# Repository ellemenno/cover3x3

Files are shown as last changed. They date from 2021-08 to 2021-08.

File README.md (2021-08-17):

# cover3x3
openscad program for a cover-up tic-tac-toe game

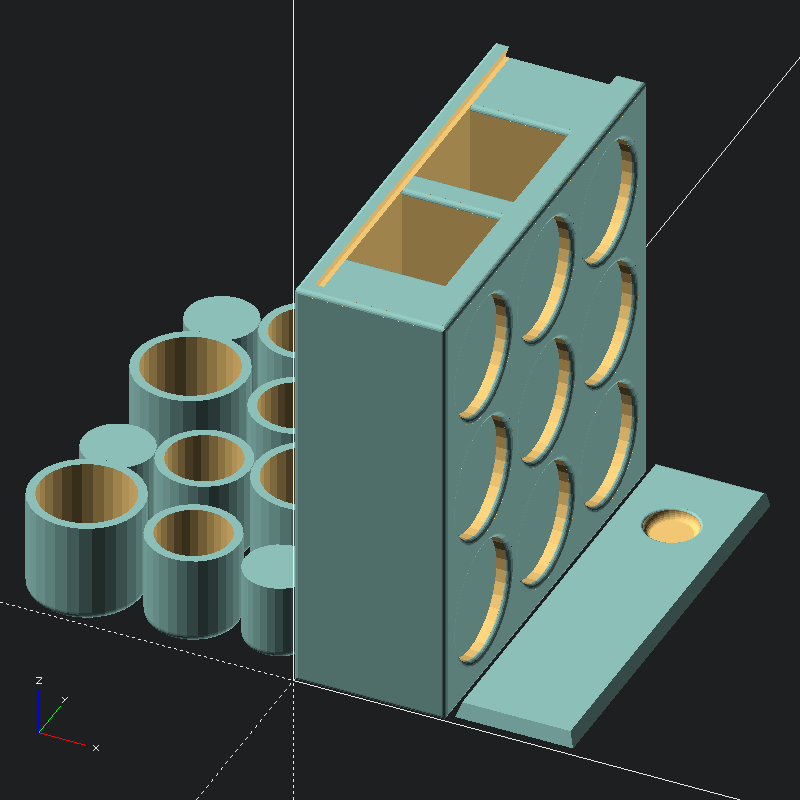
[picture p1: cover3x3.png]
cover3x3 board, box, and pieces


# pieces

* _board_ - 3x3 grid of squares, same as tic-tac-toe
* _cups_ - nesting pieces in 2 colors, each color having 2 each of 3 sizes. cups are played open side down, to cover smaller cups.
* _stack_ - a set of one or more nested cups

# rules

a game for 2 players

## start

the game starts with an empty board.

each player starts with 2 full stacks of the same color.

## play

players take turns placing cups of their color, either from one of their stacks onto the board, or from one location on the board to another.

moving from one board location to another may uncover a cup, which is then in play.

cups can be placed on empty squares, or to cover a cup of a smaller size of either color.

## finish

a player wins when there is a full row of their color, either horizontally, vertically, or diagonally.

winning may happen either as a result of a player's own move, or their opponent's.

if a position is repeted 3 times, the game ends in a draw.

# notes

* this openscad program depends on the [`slide_top_box` module][slide_top_box]
* Gobblet (4x4) and Gobblet Gobblers (3x3) are board games designed by Thierry Denoual and published by Blue Orange Games that introduced the cover mechanic.

[slide_top_box]: https://github.com/ellemenno/slide_top_box "openscad module for a sliding dovetail lidded box"
[thumbnail]: ./cover3x3.png "rendering of the game board and pieces"

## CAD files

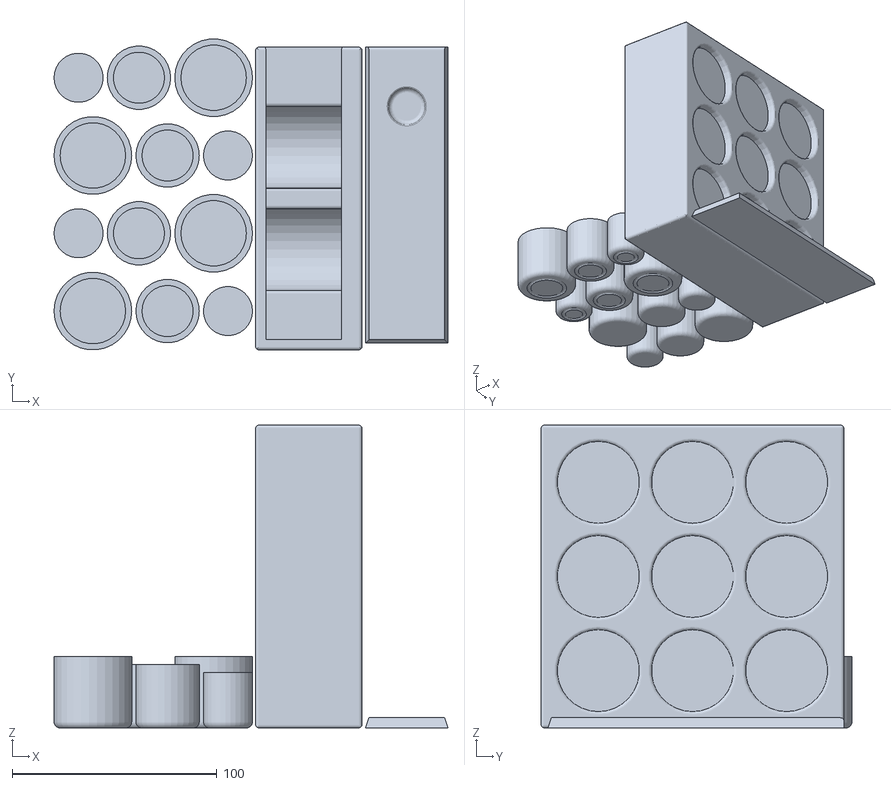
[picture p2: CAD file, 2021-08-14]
cover3x3.stl
192.5 x 151.9 x 148.0

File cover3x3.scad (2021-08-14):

//----------------------------
// cover3x3 game
// pieces fit inside gameboard
// v0.0.6


use <slide_top_box.scad>

//--- parameters

wall_thickness = 5;
piece_thickness = 3;
piece_spacing = 3;
sm_piece_diameter = 24;
air_gap = 1; // stacking clearance

// computed variables
sm = sm_piece_diameter;
md = sm+piece_thickness*2+air_gap; // medium
lg = md+piece_thickness*2+air_gap; // large
piece_height = sm_piece_diameter + piece_thickness;

board_dim = 3 * (lg+air_gap*2 + (piece_spacing*2));
box_size = slide_top_box_size(
  size=[lg_h(piece_height, piece_thickness, air_gap)+2*air_gap, board_dim, board_dim],
  thickness=wall_thickness,
  is_interior_size=true
);

//--- assembly

echo("- - - - - - - -");
echo("cover3x3");
ind = "    ";
echo(str(ind, "v0.0.6"));
echo(str(ind, "board size of ", box_size+[2*wall_thickness, 0, 0]));
echo(str(ind, [sm_piece_diameter, piece_height], "mm small piece"));
echo(str(ind, wall_thickness, "mm wall thickness"));
echo(str(ind, piece_thickness, "mm piece thickness"));
echo("- - - - - - - -");

// gameboard
color("white") box_and_gameboard(box_size, wall_thickness, [sm, md, lg], piece_spacing, air_gap);

// pieces, behind box
translate([-lg/2-piece_thickness/2, lg/2, 0]) {
  color("red")       translate([0,    0, 0]) piece_set(sm, md, lg, piece_height, piece_thickness, marked=true);
  color("royalblue") translate([0, lg*2, 0]) piece_set(sm, md, lg, piece_height, piece_thickness, marked=false);
}

//--- functions
function sm_h(h, t, a=1) = h;
function md_h(h, t, a=1) = h+t+a;
function lg_h(h, t, a=1) = h+t+a+t+a;

//--- modules

module torus(big_r=5, little_r=1.5, fs=0.5) {
  rotate_extrude($fs=fs)
  translate([big_r-little_r, 0, 0])
  circle(r=little_r, $fs=fs);
}

module round_inner(big_r=5, little_r=1.5, fs=0.5) {
  translate([0, 0, -little_r])
  difference() {
    cylinder(h=big_r, r=big_r, $fs=fs);
    torus(big_r+little_r, little_r, fs);
  }
}

module round_linear(len, f, fs=0.5) {
  translate([0, -f, -f])
  difference() {
    cube([len,f*2, f*2], center=false);
    rotate([0, 90, 0]) translate([0, 0, -len*0.05]) cylinder(h=len*1.1, r=f, $fs=fs);
  }
}

module piece(w, h, thickness, marked=true, solid=false, fs=0.5) {
  r = w/2;
  h1 = h-thickness;
  r1 = r-thickness;
  t = thickness;

  difference() {
    hull() {
      translate([0,0,t]) torus(big_r=r, little_r=t);
      translate([0, 0, h/2+t/2]) cylinder($fs=fs, h=h-t, r=r, center=true);
    }
    if (marked) {
      translate([0,0,-t/4]) torus(r*.7, t/2);
    }
    if (!solid) {
      translate([0, 0, h1/2+thickness+t]) cylinder($fs=fs, h=h, r=r1, center=true);
    }
  }
}

module piece_set(sm, md, lg, height, thickness, marked=true, air_gap=1) {
  a = air_gap;
  t = thickness;
  tt = thickness/2;
  h = height;
  gap = (lg-sm)/2;
  translate([              gap,  0, 0]) piece(sm, sm_h(h, t, a), t, marked, solid=true);
  translate([        gap-md+tt,  0, 0]) piece(md, md_h(h, t, a), t, marked);
  translate([gap-(md+lg)+tt+tt,  0, 0]) piece(lg, lg_h(h, t, a), t, marked);
  translate([                0, lg, 0]) piece(lg, lg_h(h, t, a), t, marked);
  translate([           -lg+tt, lg, 0]) piece(md, md_h(h, t, a), t, marked);
  translate([   -(lg+md)+tt+tt, lg, 0]) piece(sm, sm_h(h, t, a), t, marked, solid=true);
}

module hole_grid(diameter, spacing=2, air_gap=1, fs=0.5) {
  module hole_row(w, h, s) {
    translate([w*0+s*0*2, 0, 0]) cylinder(h=h, r=w/2, $fs=fs);
    translate([w*1+s*1*2, 0, 0]) cylinder(h=h, r=w/2, $fs=fs);
    translate([w*2+s*2*2, 0, 0]) cylinder(h=h, r=w/2, $fs=fs);
  }
  w = diameter + air_gap*2;
  r = w/2;
  translate([r+spacing, r+spacing, 0]) {
    translate([0, w*0+spacing*0*2, 0]) hole_row(w, diameter, spacing);
    translate([0, w*1+spacing*1*2, 0]) hole_row(w, diameter, spacing);
    translate([0, w*2+spacing*2*2, 0]) hole_row(w, diameter, spacing);
  }
}

module rounder_grid(diameter, spacing=2, air_gap=1, f=3) {
  module rounder_row(w, r, s, f) {
    translate([w*0+s*0*2, 0, 0]) round_inner(r, f);
    translate([w*1+s*1*2, 0, 0]) round_inner(r, f);
    translate([w*2+s*2*2, 0, 0]) round_inner(r, f);
  }
  w = diameter + air_gap*2;
  r = w/2;
  translate([r+spacing, r+spacing, 0]) {
    translate([0, w*0+spacing*0*2, 0]) rounder_row(w, r+f, spacing, f);
    translate([0, w*1+spacing*1*2, 0]) rounder_row(w, r+f, spacing, f);
    translate([0, w*2+spacing*2*2, 0]) rounder_row(w, r+f, spacing, f);
  }
}

module piece_holder(box_size, r, t, a, f, fs=0.5) {
  // r: piece radius
  // t: wall thickness
  // a: air gap
  x = box_size.x-t*2; // box cavity height (i.e. piece height + air gap)
  yy = (box_size.y - (r+t+a)*4) / 2; // distance from edge of box to holder
  zz = box_size.z - (t+r+a+r+t)*2-t; // distance from bottom of holder to bottom of box

  module u_holder() {
    difference() {
      hull() {
        translate([0, (r+t+a), (r+t+a)+r/2+t]) rotate([0, 90, 0]) cylinder(h=x, r=r+t+a, $fs=fs);
        translate([0, 0, (r+t+a)*2]) cube([x, (r+t+a)*2, (r+t+a)*2]);
      }
      translate([-a, t, t])
      hull() {
        translate([0, r+a, r+a+r/2+t]) rotate([0, 90, 0]) cylinder(h=x+a*2, r=r+a, $fs=fs);
        translate([0, 0, (r+t+t)*2]) cube([x+a*2, (r+a)*2, (r+a)*2]);
      }
    }
  }

  difference() {
    union() {
      cube([x, yy, t]);
      translate([0, yy, 0]) {
        zzz = -(r+t+a)*4+t;
        translate([0, 0, zzz]) u_holder();
        translate([0, (r+t+a)*2, zzz]) u_holder();
        translate([0, (r+t+a)-t/2, zzz-zz+t/2]) cube([x, t, zz +r/2+t]);
        translate([0, (r+t+a)-t/2 + (r+t+a)*2, zzz-zz+t/2]) cube([x, t, zz +r/2+t]);
      }
      translate([0, yy+((r+t+a)*4), 0]) cube([x, yy, t]);
    }

    gap = a+r+r+a;
    translate([0, yy+t, t]) rotate([ 0, 0, 0]) round_linear(x, f);
    translate([0, yy+t+gap, t]) rotate([90, 0, 0]) round_linear(x, f);
    translate([0, yy+t+gap+t+t, t]) rotate([ 0, 0, 0]) round_linear(x, f);
    translate([0, yy+t+gap+t+t+gap, t]) rotate([90, 0, 0]) round_linear(x, f);
  }
}

module box_and_gameboard(box_size, wall_thickness, pieces, piece_spacing, air_gap) {
  x = box_size.x + wall_thickness;
  y = box_size.y;
  z = box_size.z;
  f = wall_thickness/3;
  sm = pieces[0];
  md = pieces[1];
  lg = pieces[2];

  difference() {
    union() {
      // box base
      slide_top_box(box_size, wall_thickness, f);
      // piece holder
      translate([wall_thickness, 0, box_size.z-wall_thickness*2]) piece_holder(box_size, lg/2, wall_thickness, air_gap, f);
      // piece plate, minus holes, then rounded inner edges
      translate([box_size.x, 0, 0])
      difference() {
        cube([wall_thickness, box_size.y, box_size.z]);
        translate([0, 0, box_size.z-wall_thickness]) {
          translate([0, wall_thickness, 0]) rotate([0, 90, 0]) hole_grid(lg, piece_spacing, air_gap);
          translate([wall_thickness, wall_thickness, 0]) rotate([0, 90, 0]) rounder_grid(lg, piece_spacing, air_gap, f);
        }
      }
    }

    translate([0, y, 0]) rotate([-90,   0,   0]) round_linear(x, f);
    translate([0, y, z]) rotate([  0,   0,   0]) round_linear(x, f);
    translate([0, 0, z]) rotate([ 90,   0,   0]) round_linear(x, f);
    translate([0, 0, 0]) rotate([180,   0,   0]) round_linear(x, f);

    translate([0, 0, z]) rotate([  0,   0,  90]) round_linear(y, f);
    translate([x, 0, z]) rotate([ 90,   0,  90]) round_linear(y, f);
    translate([x, 0, 0]) rotate([180,   0,  90]) round_linear(y, f);
    translate([0, 0, 0]) rotate([-90,   0,  90]) round_linear(y, f);

    translate([0, y, 0]) rotate([  0, -90,   0]) round_linear(z, f);
    translate([x, y, 0]) rotate([  0, -90, -90]) round_linear(z, f);
    translate([x, 0, 0]) rotate([  0, -90, 180]) round_linear(z, f);
    translate([0, 0, 0]) rotate([  0, -90,  90]) round_linear(z, f);
  }

  // lid, in front of box
  lid_size = slide_top_lid_size(box_size, wall_thickness);
  translate([box_size.x+(2/3*wall_thickness), 0, 0]) {
    difference() {
      slide_top_lid(
        size=lid_size,
        thickness=wall_thickness,
        ridge=f,
        has_finger_recess=false
      );
      // rounded outer edge
      translate([0, lid_size.y, lid_size.z]) rotate([0, 0, 0]) round_linear(lid_size.x, f);
      // custom finger notch shaped like pieces
      translate([lid_size.x/2, lid_size.y-sm-wall_thickness, 1/3*wall_thickness]) scale([.75, .75, 1]) {
        piece(sm, wall_thickness*2, piece_thickness, marked=false, solid=true);
        translate([0, 0, wall_thickness-f]) round_inner(sm/2+2/3*f, f);
      }
    }
  }
}

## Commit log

2021-07-27 v0.0.1
    all the main bits, but with sharp corners and no interior forms to
    hold the pieces. also not print tested yet.
    [cover3x3.scad]
2021-07-29 add rounder top edges and add optional marks to pieces
    [cover3x3.scad]
2021-07-31 add rounded inner edges to gameboard holes
    [cover3x3.scad]
2021-07-31 add rounded edges to box base and lid front
    [cover3x3.scad]
2021-07-31 add metadata for print volume
    [cover3x3.scad]
2021-08-01 re-center piece divots in board plate; increase spacing between
    [cover3x3.scad]
2021-08-02 add piece holder insert
    [cover3x3.scad]
2021-08-02 simplify piece dimensions; round piece holder edges
    [cover3x3.scad]
2021-08-14 improvements after first printing - avoid slope on finger recess in lid to avoid stairstepping - correct depth of piece holders - shorten air gap between stacking pieces - correct width of lid opening
    [cover3x3.scad]
